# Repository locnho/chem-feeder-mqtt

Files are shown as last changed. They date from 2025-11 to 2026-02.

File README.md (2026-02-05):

# Chem Feeder MQTT

This project provides detection of Pool pH value and report to AquaLinkD via MQTT service.

 * Using a camera to capture the pH controller screen
 * Extract the pH value from the LCD 7 segment display
 * Make a connection to the MQTT service to publish the pH value
 * Report pH controller alarm to MQTT service
 * Report Acid tank level to MQTT service

This work makes use of https://github.com/ved-sharma/Digits_recognition_OpenCV_Python and https://pyimagesearch.com/2018/09/17/opencv-ocr-and-text-recognition-with-tesseract.

Currently, there are two vesions - Python and C++. The Python version is tested and updated. The C++ version is outdated.

# Hardware
The hardware includes:

* Raspberry PI 5
* Hanna BL100 Pool & Spa Ph Controller/Dosing pump
* Arducam for Raspberry Pi Camera Module 3 Wide, 120° IMX708 Manual Focus with M12 Lens (need manual focus)
* RPI heat sink (GeeekPi Aluminum Heatsink Case for Raspberry Pi 5, Aluminum Alloy Armor Case, Passive Cooling Case)

The Raspbery PI 5 also runs AqualinkD.

## Acid Tank Sensor

For Acid Tank sensor, preferred non-contact sensor such:

* XKC-Y25-V Non Contact Liquid Level Sensor (https://www.amazon.com/dp/B0C73F96MF?ref=ppx_yo2ov_dt_b_fed_asin_title) - 2 totals
* KeeYees 10pcs 4 Channels IIC I2C Logic Level Converter Bi-Directional Module 3.3V to 5V Shifter (https://www.amazon.com/dp/B07LG646VS?ref=ppx_yo2ov_dt_b_fed_asin_title)
* IP68 Waterproof Junction Box Housing (https://www.amazon.com/dp/B0CP88ZFWL?ref=ppx_yo2ov_dt_b_fed_asin_title&th=1)
* JST XH 2.54 MM Connector Kit (https://www.amazon.com/dp/B0F5QBR5F4?ref=ppx_yo2ov_dt_b_fed_asin_title&th=1)

This requires a level shifter as the sensor voltage is 5V and RPI 5 requires 3.3V. Then create the adapter board with JST connector. See images below:

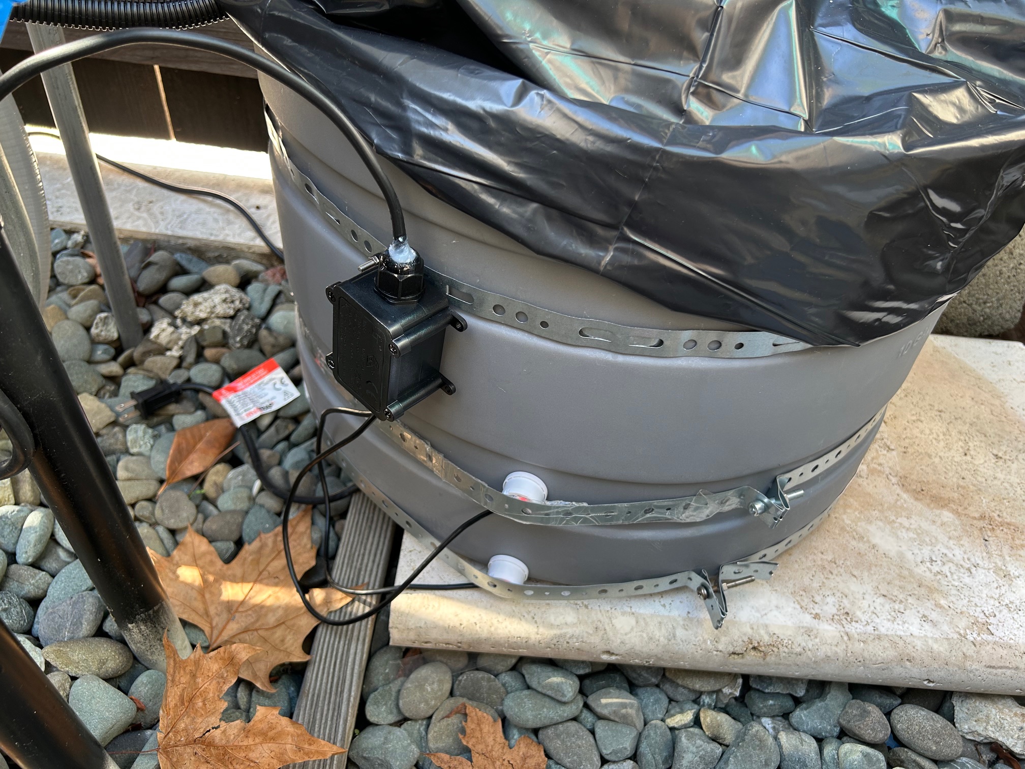
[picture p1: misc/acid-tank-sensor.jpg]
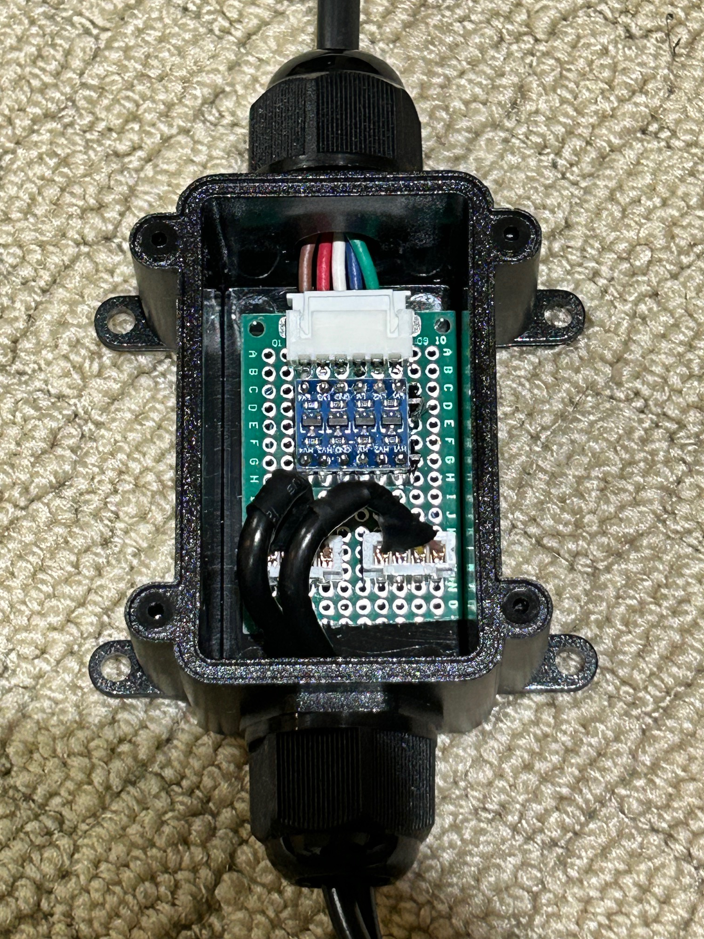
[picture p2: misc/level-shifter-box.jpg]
 | 

To ensure that the junction box is sealed, apply some window sealant on the wire exit.

## Relay & Wiring Diagram

The Acid Dosing Controller can dangerous. As such the following safety measures are employed:

* Acid Dosing Controller is enabled only if the system is in Pool mode
* Acid injector is mounted at the Pool return pipe only
* Sensor is used to ensure that the Acid Dosing Controller is only enabled if the pump is actually running
* A timer to limit the amound of time the Acid Dosing Controller is enabled (avoid hardwaer malfunction and dump a large amount of acid to the pool)

To implement the above, the following hardwares are used:

* A 12V dual relay to disable Acid Dosing Controller if it is NOT in pool mode and no water flow
* A 12V 7 day timer

12V is used as fan are also 12V. Fan can be added to cool the electronic in the enclosure box. The wire diagram is shown below.

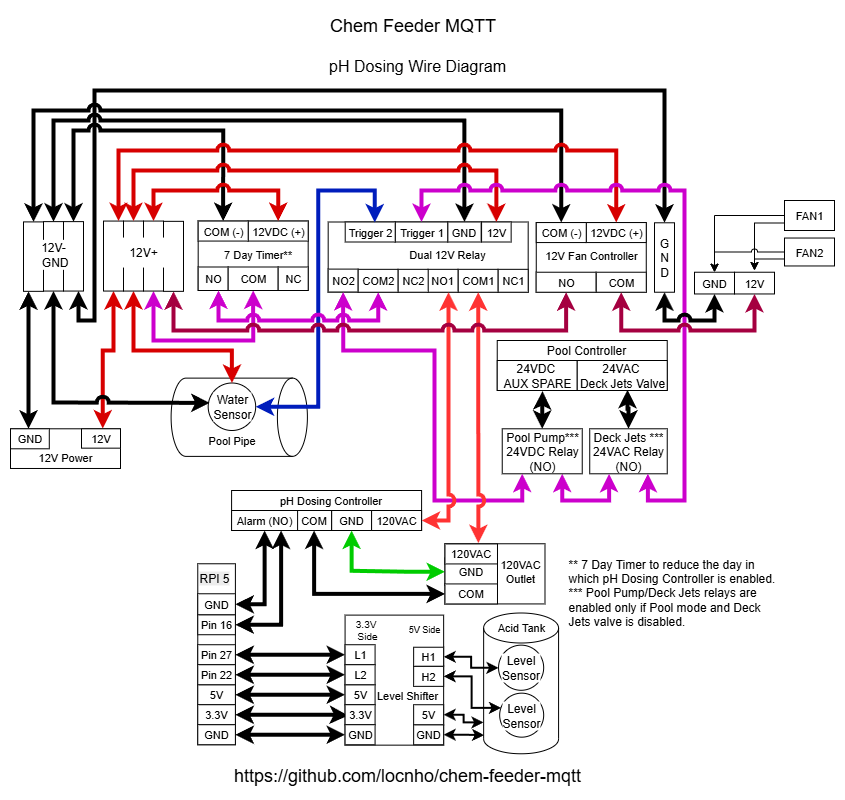
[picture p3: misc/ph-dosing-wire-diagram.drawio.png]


## Mounting

To mount various hardware, use Aluminum DIN Rails (https://en.wikipedia.org/wiki/DIN_rail).

The folder "models" includes various 3D print models for DIN rail mounting.

# pH Report Values

| pH | Description |
|---|---|
|  0.0 | Unit is powered off or no LCD display |
|  1.0 | Unable to detect LCD correctly |
|  2.0 | Unable to detect digits correctly |
|  other values | Values as reported by the unit |

Alarm is reported via the web site interface. Refer to section "Enable pH Data Logging and Web Page".

# How to position the camera?

You need to position the camera such that it captures the outer square outline of the LCD screen.
Refer to image below as an exmpale:

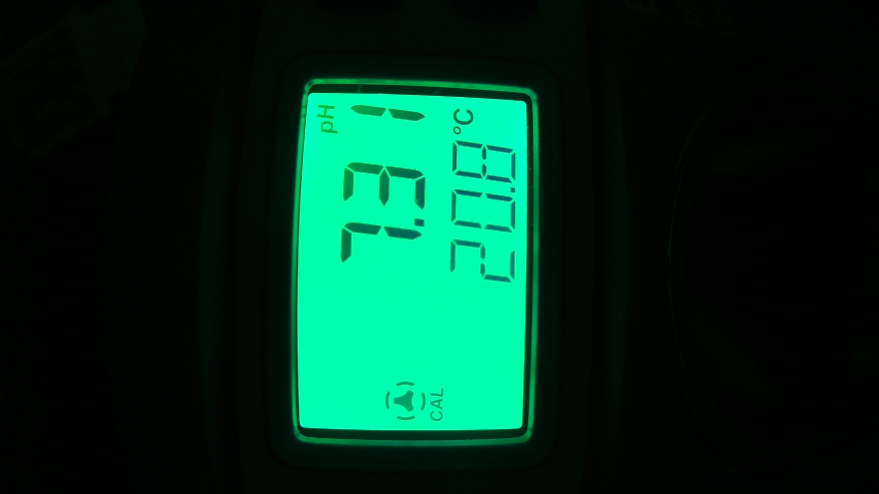
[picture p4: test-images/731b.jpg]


You can run this application to have a live view from browser:

``
    python ./src/rpicam-stream.py
``

Then, on the browser: 

``
    http://<ip address>:5000
``

Below is an image of the pH Controller and RPI camera mount:

To mount the camera over the LCD display, use galvanized interlocking hanger strap. I strapped my pH tank with this. Wrap the hanger strap with some transparent tape. Then bend and squeeze in between the RPI heat sink. There is also mounting 3D models located at folder models. This will make adjust much simple.

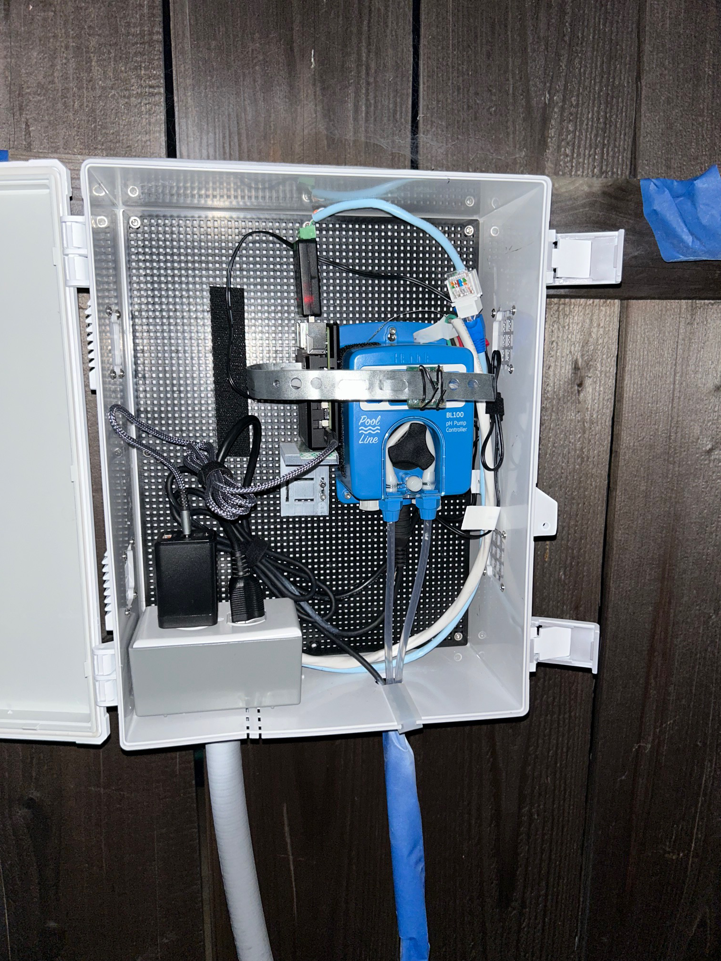
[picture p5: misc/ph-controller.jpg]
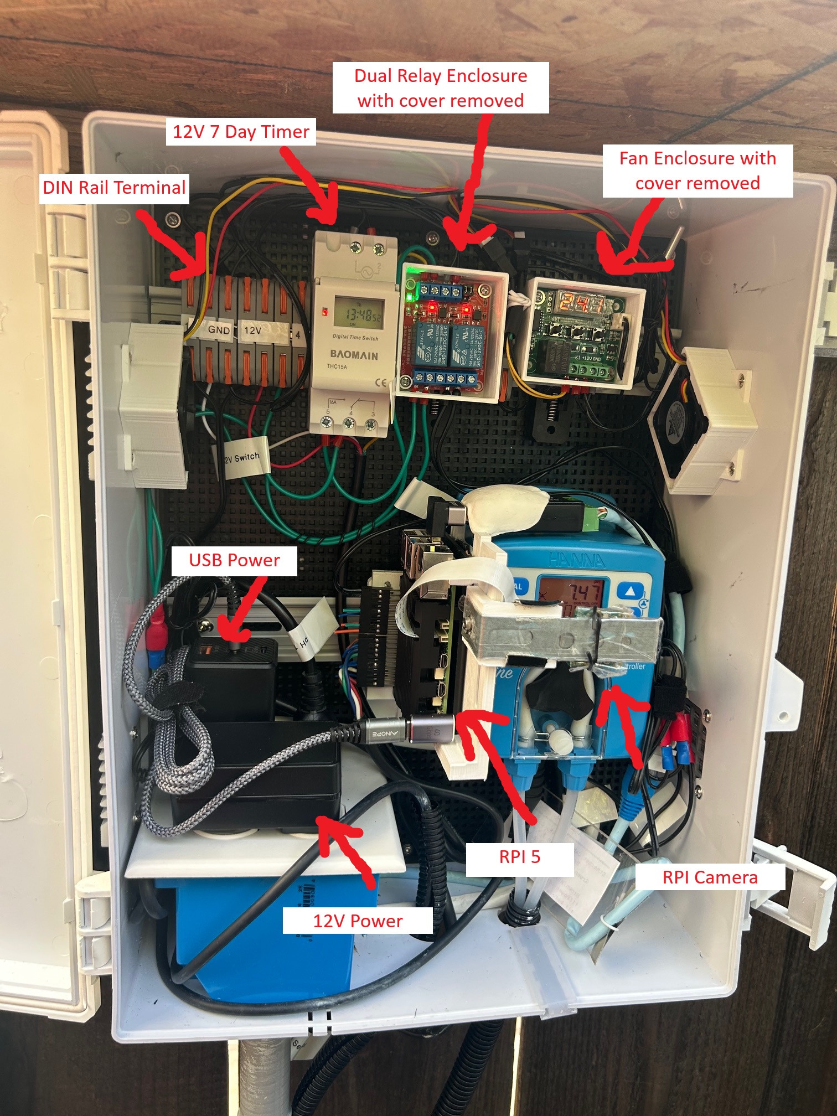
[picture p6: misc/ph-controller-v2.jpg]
 | 

# Configuration with RPI GPIO

GPIO Pin 26 - Alarm: This pin is used to detect pH controller alarm (active high). Connect to controller Normal Open (NO) side.

GPIO Pin 27 - Acid Tank Level1: When this is asserted low, acid tank is below 1%.

GPIO Pin 22 - Acid Tank Level2: When this is asserted low, acid tank is below 50%.

Use this command to enable GPIO:

```
python ./ph-chem-feeder.py --mqtt --password "change to your password" --gpio
```

Use this command to enable and change GPIO pin:

```
python ./ph-chem-feeder.py --mqtt --password "change to your password" --gpio <alarm pin> <acid level1> <acid level2>
```

If you need more options, run with argument "--help".

# Cropping Image

Due to LED of various electronic, you may need to crop the image using the argument "--crop" or cover these LEDs. This argument will crop from four sides.

This command will crop the left side by 400 pixels.

```
python ./ph-chem-feeder.py --crop 400 0 0 0 --mqtt --password "change to your password" 

```

# Configure to start at system boot

See scripts/chem-feeder-mqtt.service

# Enable pH Data Logging and Web Page

To record pH reading for view on a web page, you must enable data logging as follow:

```
python3 ph-chem-feeder.py --gpio --mqtt --password <your password> --gpio --datalog /home/pi/chem-data.bin

```

When pH value is changed from previous value, it saved to the datalog file. All non-zero pH value is only saved every 15 minutes. 

The data can be view from a web page as follow:

```
http://<ip address>:8025

```

Below is an screen shoot of the web page.

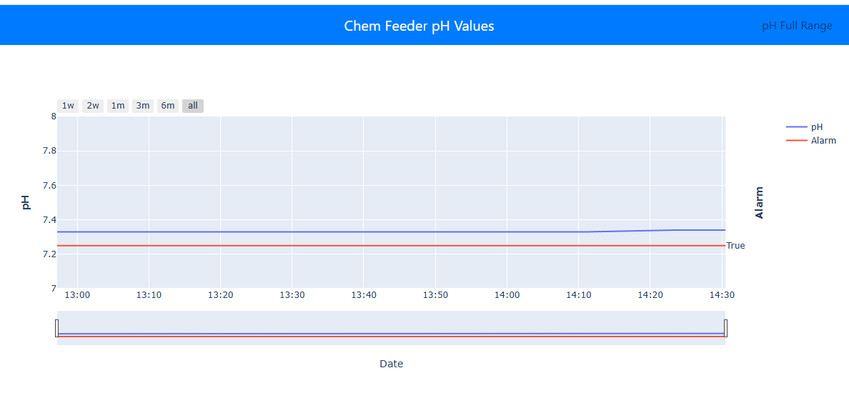
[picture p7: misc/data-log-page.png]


# What to do if it is not detecting digits correctly?

So far, it seems to be functionaly correctly. If you need to tune for your LCD display, try the following:

1. Using rpicam-still application, capture some images.
2. Edit ph-chem-feeder.py and set DBG_LEVEL to "1 + 2 + 4".
3. Disable "PICAM" and "RPIGPIO" by set them to 0.
4. Run this command on your PC or Linux with desktop GUI:

   python ./ph-chem-feeder.py -f "path to your image"

This will show you what the image looks like. 

First, make sure that the detection of the screen is correct. It should crop to just the LCD screen. Refer to image below:

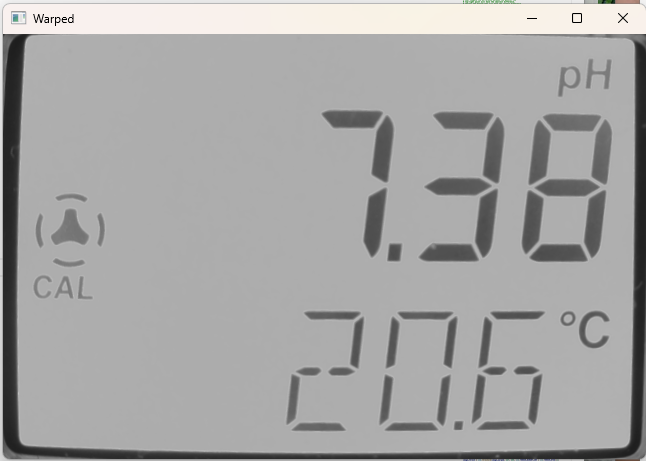
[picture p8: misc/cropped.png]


Second, make sure that each digit has a rectangle draw on it. This indicates that it detected the location of the 3 digits.

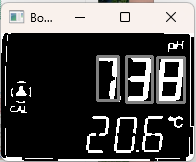
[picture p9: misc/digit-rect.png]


Finally, the decode of each digits. This last part should just work. Otherwise you will need to adjust the detection of the individual segment by changing this code fragment:

```
        # define the set of 7 segments
        segments = [
            ((0, 0), (w, dH)),							 # top
            ((2, 0), (dW + 2, h // 2)),					 # top-left
            ((w - dW - 2, 0), (w, h // 2)), 			 # top-right
            ((0, (h // 2) - dHC), (w, (h // 2) + dHC)),  # center
            ((0, h // 2), (dW, h)),						 # bottom-left
            ((w - dW*2, h // 2), (w - 2, h)),		     # bottom-right
            ((0, h - dH), (w, h))					     # bottom
        ]
```

# Run Regression Testing

To run a regression testing with all images in folder test-images with first 3 letters as digit, issue the following command:

```
    python .\src\ph-chem-feeder.py -r 90 --selftest
    Chem Feeder MQTT
    PASSED 17/17
```

# Background on the Overall Algorithm

The general idea is:

1. Capture 20 images with delay of 50ms
2. Using these images, determine if the LCD is ON or OFF. This is for the case where the LCD is flashing due to alarm.
3. If it is OFF, report 0.0 and stop
4. For image that is not complete black, determine the LCD location and crop 100 pixel borders
5. Determine the contour of the LCD using OpenCV
6. Scale the image to 512 pixel and transpose the LCD image into a rectangle using OpenCV
7. Scale the image to 128 pixel and determine all the LCD digits using OpenCV
8. For each LCD digits, determine whether each segment is ON (white) or OFF (black). Then decode the digit from these on/off segment.
9. If the operation failed to determine the digits or transpose, adjust the black and white binary mapping threshold and try again.
10. If the operation failed to determine the digits, adjust the exposure and try again.
11. Final, try three times.
12. If all failed, report 2.0 for error decoding digits.

# Homebridge MQTT Integration for Acid Tank Level & Alarm

To report Acid Tank Level and Alarm in HomeKit, install the homebridge-mqtt plugin (https://github.com/cflurin/homebridge-mqtt).

The configuration setting:

```
        {
            "name": "mqtt",
            "url": "mqtt://127.0.0.1",
            "port": "1883",
            "username": "pi",
            "password": "password",
            "qos": 0,
            "topic_type": "multiple",
            "topic_prefix": "homebridge",
            "platform": "mqtt"
        }
```

# AquaLinkD Web Page Integration for Acid Tank Level & Alarm

To have Acid Tank Level and Alarm display in AquaLinkD, you need to use this branch:

https://github.com/locnho/AqualinkD/tree/pda-ps6-dev-v3.0.3b

Or you can manual add support to your existent AquaLinkD Web Page:

1. Copy file "web/mqtt_sensors.js" and "web/mqtt.min.js" to "/var/www/aqualinkd"
2. Add below line to "/var/www/aqualinkd/index.html" right above "<script type='text/javascript'>"

   <script scr="mqtt.min.js" type="text/javascript"></script>
3. Add below line to "/var/www/aqualinkd/config.json"

   "external_script":"mqtt_sensors.js",

Or you can just build this and do a "make install".

# ORP Monitor Support

It now supports for MQTT ORP monitor with AquaLinkD. If you publish ORP reading to AquaLinkD, it can monitor ORP values.

 If you want to disable, add argument:

```

    --orp ""

```

# Misc Note

If your camera is mounted at a different direction, use the "-r" parameter to rotate.

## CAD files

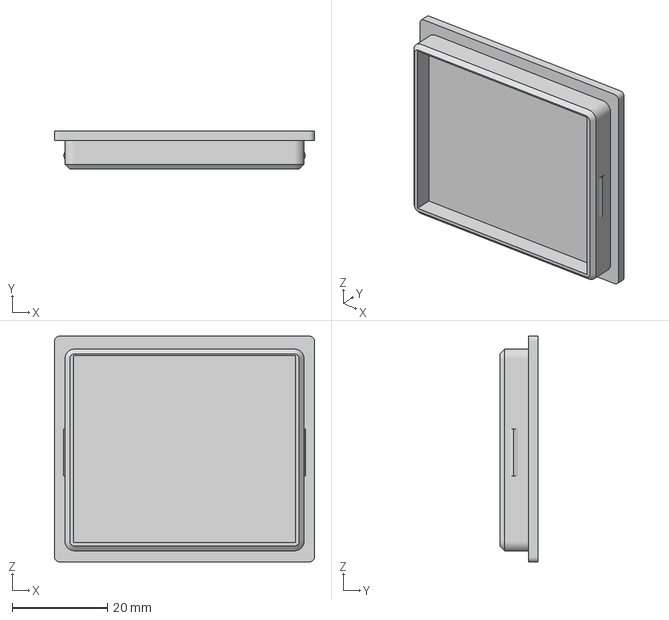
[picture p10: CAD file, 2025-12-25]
models/DIN Rail Fan Enclosure Cover.3mf
54.5 x 8.00 x 47.3 mm

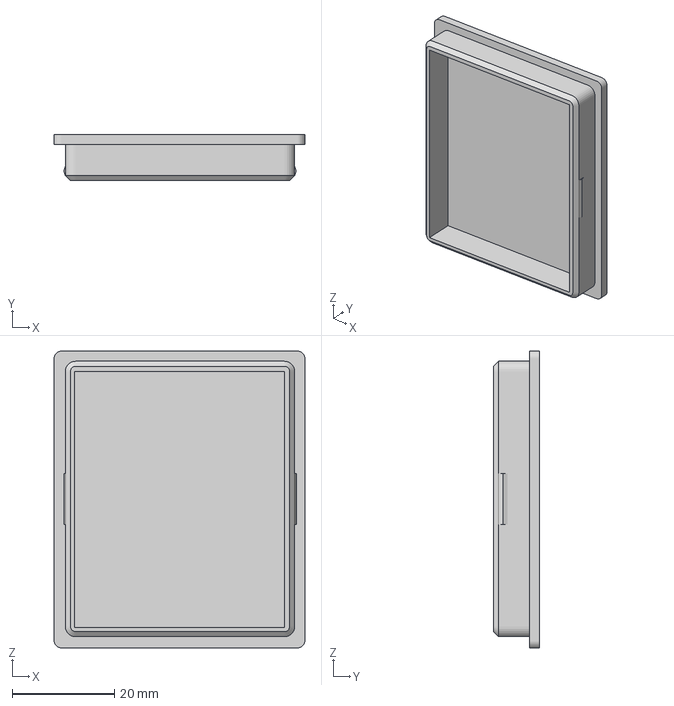
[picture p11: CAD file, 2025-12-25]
models/DIN Rail Dual Relay Cover.3mf
49.0 x 9.00 x 58.0 mm

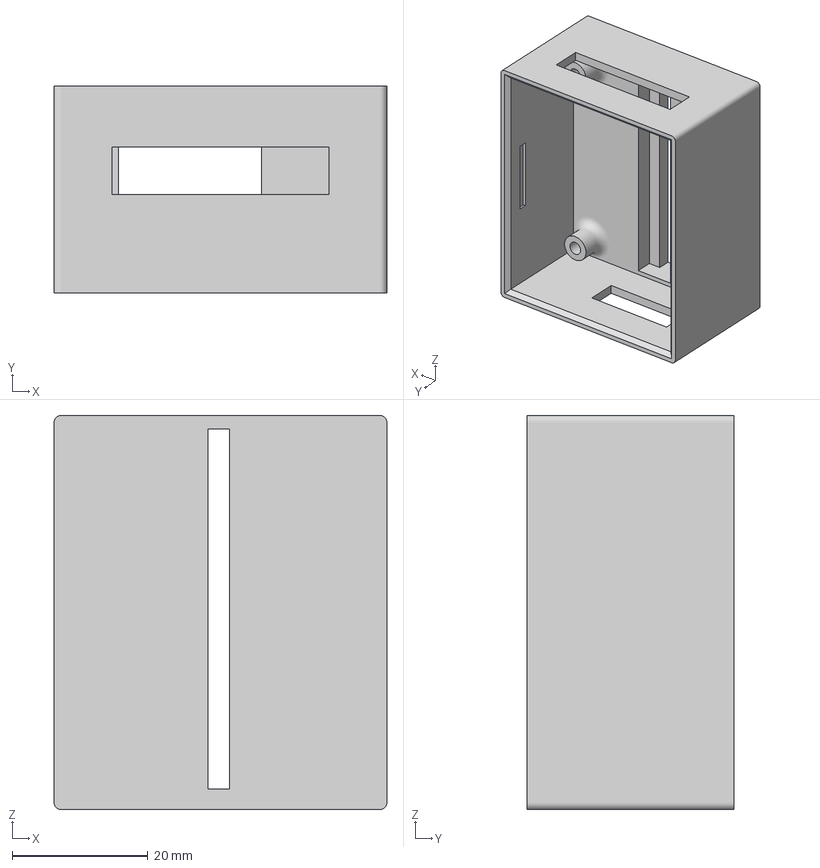
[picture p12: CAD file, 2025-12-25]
models/DIN Rail Dual Relay Enclosure.3mf
49.0 x 30.5 x 58.0 mm

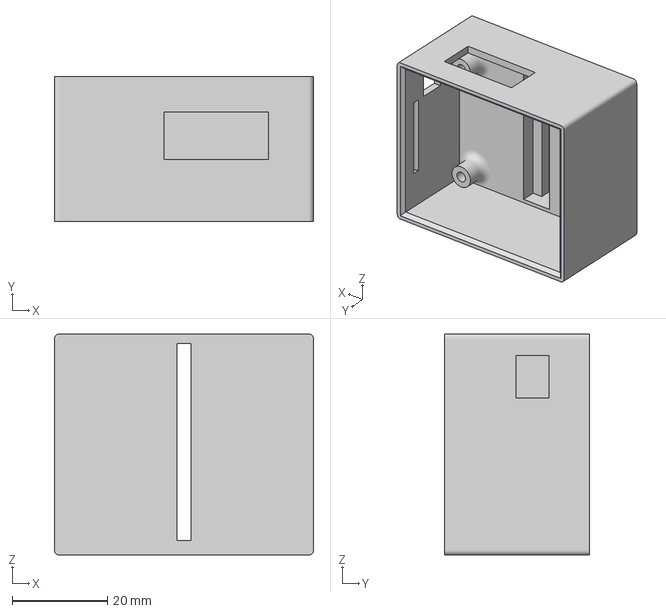
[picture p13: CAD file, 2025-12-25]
models/DIN Rail Fan Controller Enclosure.3mf
54.5 x 30.5 x 46.5 mm

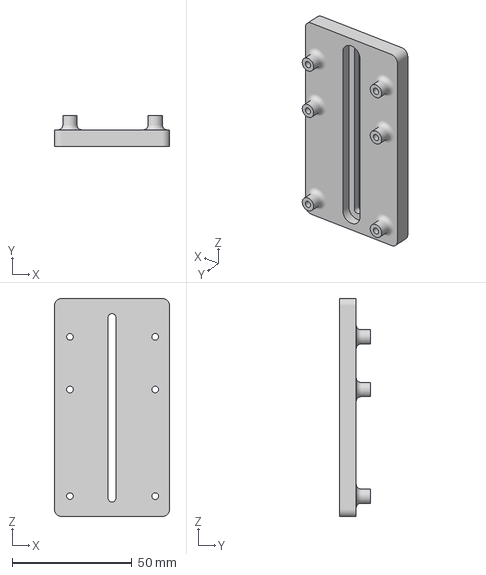
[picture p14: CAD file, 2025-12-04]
models/DIN Rail Dual Relay Mount Extended.3mf
48.1 x 13.0 x 91.0 mm

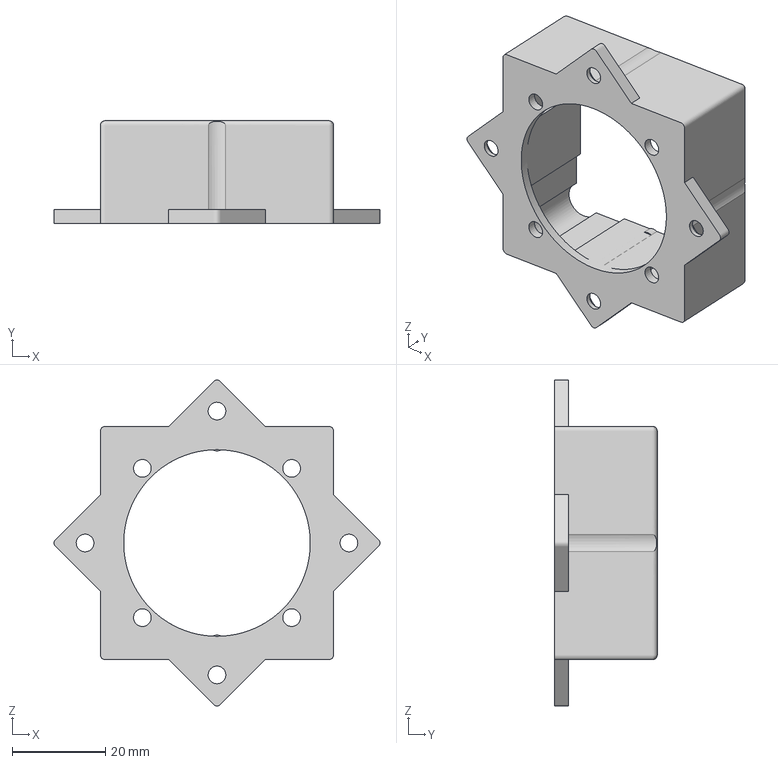
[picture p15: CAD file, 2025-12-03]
models/40mm Fan Mount.3mf
69.9 x 22.0 x 69.9 mm

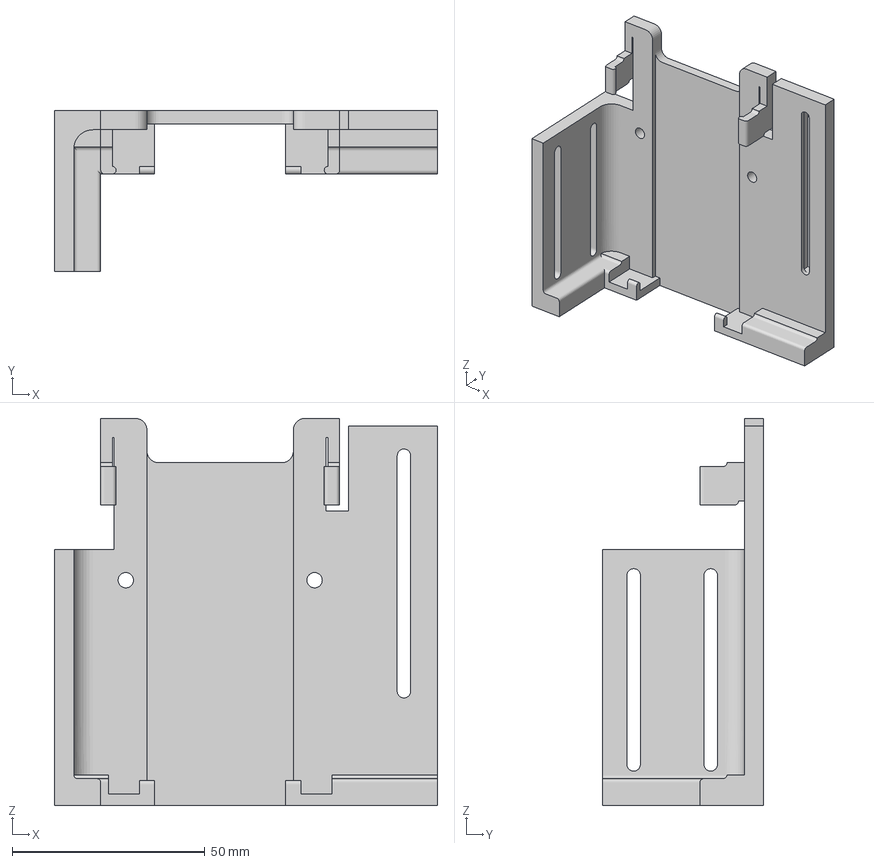
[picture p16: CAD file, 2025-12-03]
models/RPI5 Side Mount.3mf
99.4 x 41.8 x 100.5 mm

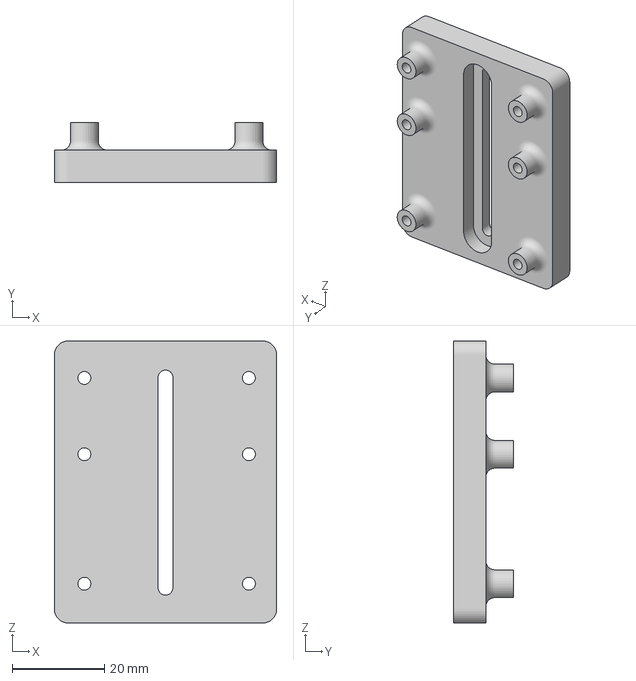
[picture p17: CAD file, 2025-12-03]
models/DIN Rail Dual Relay Mount - 35.5x44.3mf
48.1 x 13.0 x 61.0 mm

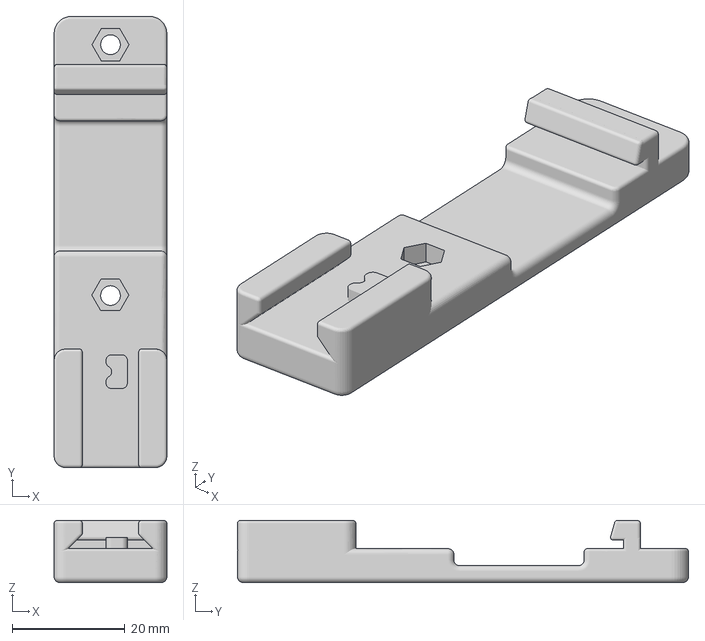
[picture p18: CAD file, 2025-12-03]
models/DIN Mount Clip - Part 2.3mf
20.0 x 80.0 x 11.0 mm

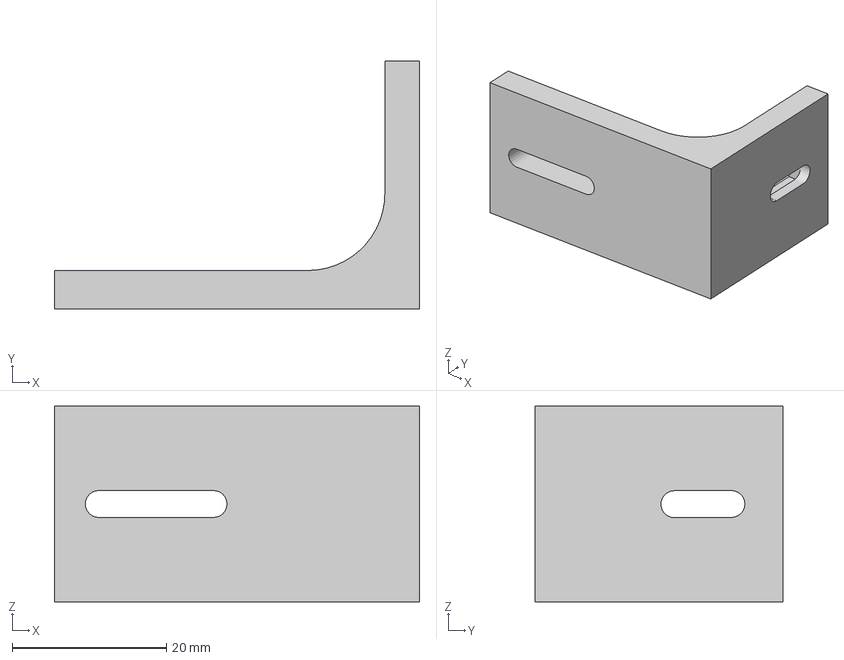
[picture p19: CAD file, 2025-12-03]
models/RPI5 Side Camera Mount.3mf
47.4 x 32.2 x 25.4 mm

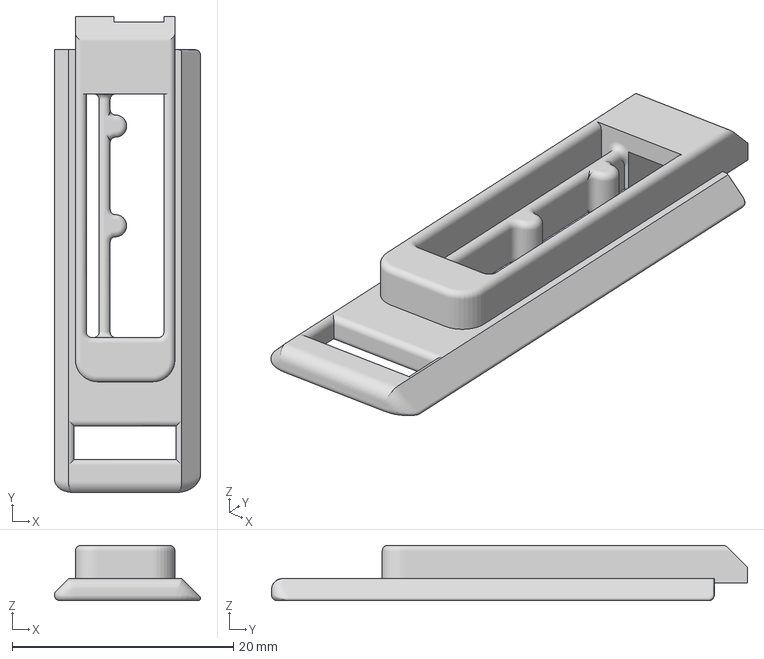
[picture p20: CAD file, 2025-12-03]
models/DIN Mount Clip - Part 1.3mf
13.2 x 43.0 x 5.00 mm

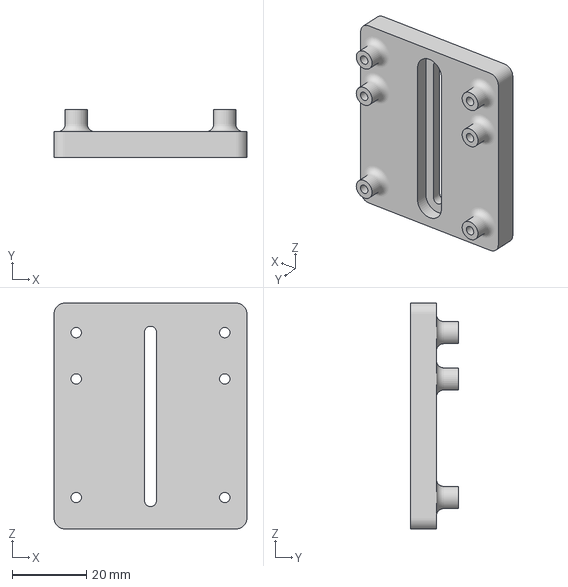
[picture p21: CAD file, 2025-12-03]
models/DIN Rail Dual Relay Mount - 40x32.3mf
52.1 x 13.0 x 61.0 mm

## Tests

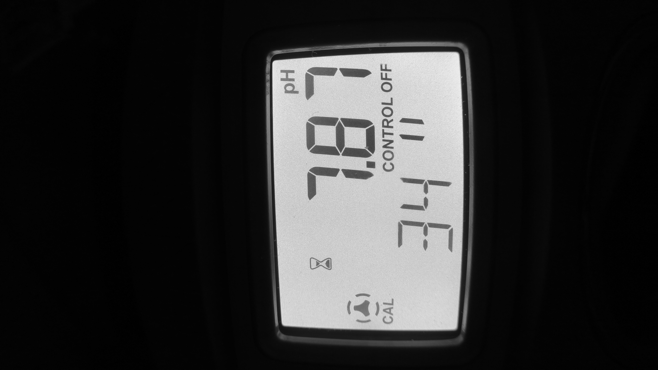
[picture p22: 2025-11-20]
test-images/787b.jpg

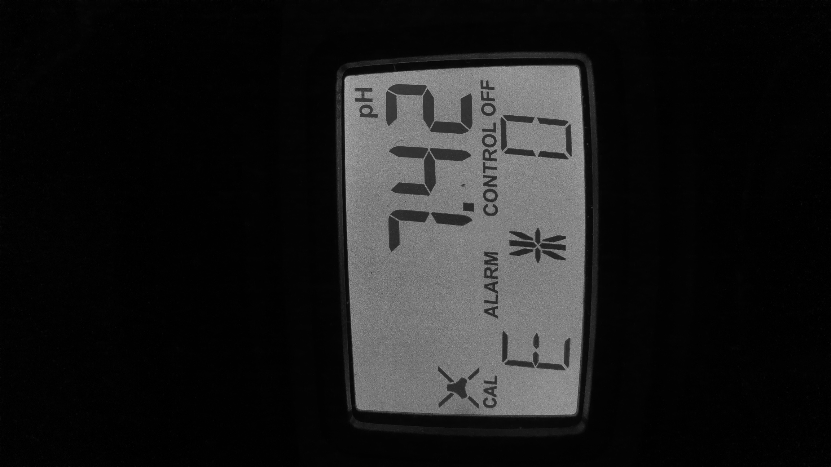
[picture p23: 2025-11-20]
test-images/742o.jpg

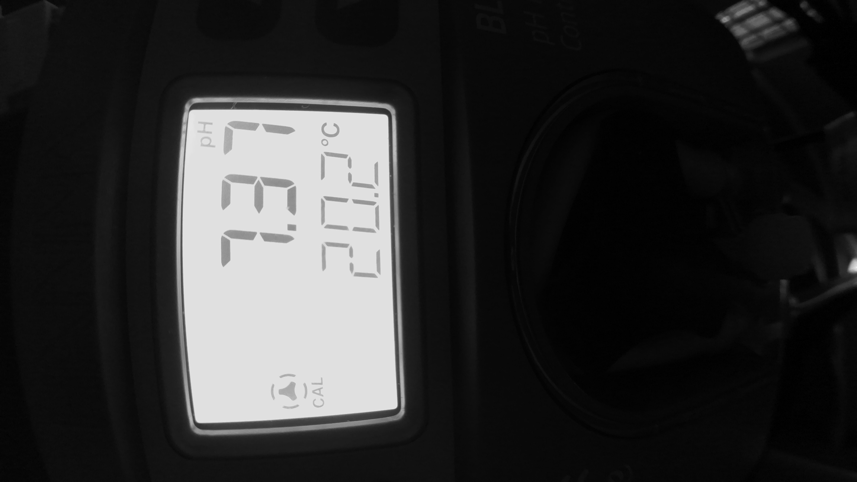
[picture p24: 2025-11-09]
test-images/737f.jpg

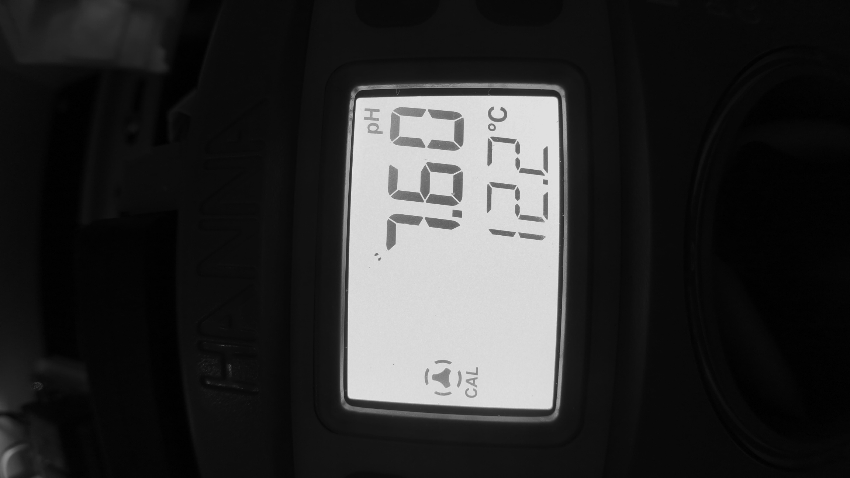
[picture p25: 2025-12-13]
test-images/760b.jpg

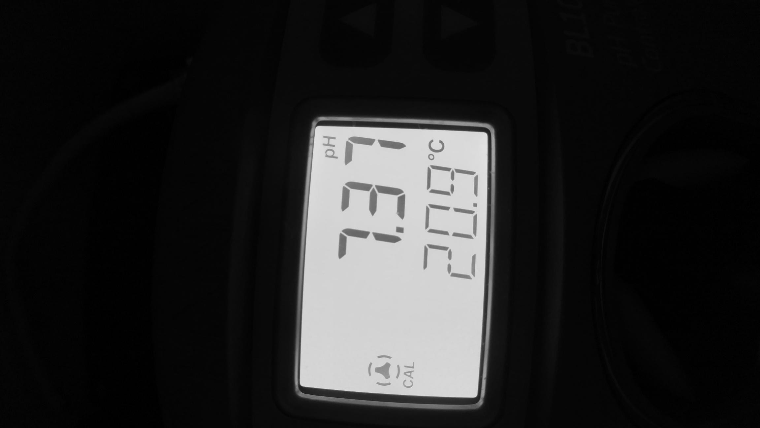
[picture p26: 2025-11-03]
test-images/737c.jpg

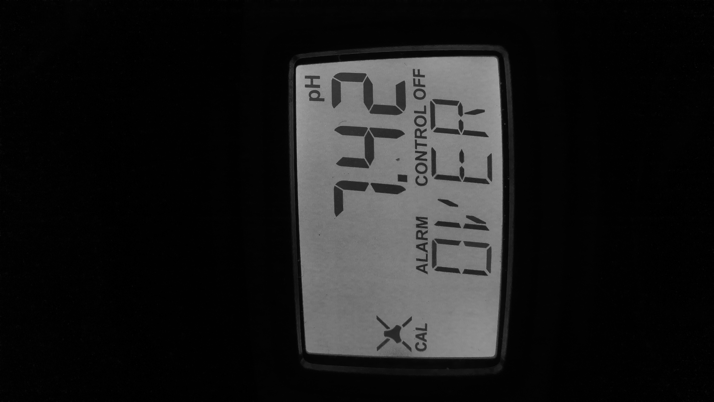
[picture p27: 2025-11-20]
test-images/742s.jpg

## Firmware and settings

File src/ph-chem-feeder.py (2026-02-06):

import argparse
import cv2
import imutils
import numpy as np
#import pytesseract
import time
import os
import csv
import paho.mqtt.client as mqtt
from datetime import datetime, timedelta
from dateutil.relativedelta import relativedelta
import pandas as pd
import math
import glob

import threading
import plotly.io as pio                     # For convert plotly to HTML
import plotly.graph_objects as go
from plotly.subplots import make_subplots
from fastapi import FastAPI
from fastapi.responses import HTMLResponse
import uvicorn
import sqlite3
import serial


PICAM = 1                 # Set to 1 to support RPI Camera, otherise, use the -f argument
RPIGPIO = 1               # Set to 1 to support GPIO pin below. Must include the --gpio argument as well
gpio_alarm_pin = 26       # physical GPIO board number for pH alarm detection (active low). Set to -1 to ignore
gpio_acid_level_pin1 = 27 # physical GPIO board number for acid tank level low. Set to -1 to ignore
gpio_acid_level_pin2 = 22 # physical GPIO board number for acid tank at 50%. Set to -1 to ignore

DBG_LEVEL = 0                       # No debugging
#DBG_LEVEL = 1                      # Show image of detecting the LCD rectangle
#DBG_LEVEL = 2                      # Show image of detecting the digit rectangle
#DBG_LEVEL = 4                      # Show info and image of detection the individual digit
#DBG_LEVEL = 8                      # Show data saving
#DBG_LEVEL = 16                     # Show GPIO info
#DBG_LEVEL = 32                     # Show each iteration of decoding an image
#DBG_LEVEL = 64                     # Show ORP information
#DBG_LEVEL = 1 + 2 + 4 + 8 + 16     # Show all

verbose = 1             # 1 - mimimum
verbose = 1 + 2         # plus MQTT publish
#verbose = 1 + 2 + 4     # plus all MQTT message


def sort_contours(cnts, method="left-to-right"):
	# initialize the reverse flag and sort index
	reverse = False
	i = 0
	# handle if we need to sort in reverse
	if method == "right-to-left" or method == "bottom-to-top":
		reverse = True
	# handle if we are sorting against the y-coordinate rather than
	# the x-coordinate of the bounding box
	if method == "top-to-bottom" or method == "bottom-to-top":
		i = 1
	# construct the list of bounding boxes and sort them from top to
	# bottom
	boundingBoxes = [cv2.boundingRect(c) for c in cnts]
	(cnts, boundingBoxes) = zip(*sorted(zip(cnts, boundingBoxes),
		key=lambda b:b[1][i], reverse=reverse))
	# return the list of sorted contours and bounding boxes
	return (cnts, boundingBoxes)

def order_points(pts):
	# initialzie a list of coordinates that will be ordered
	# such that the first entry in the list is the top-left,
	# the second entry is the top-right, the third is the
	# bottom-right, and the fourth is the bottom-left
	rect = np.zeros((4, 2), dtype = "float32")
	# the top-left point will have the smallest sum, whereas
	# the bottom-right point will have the largest sum
	s = pts.sum(axis = 1)
	rect[0] = pts[np.argmin(s)]
	rect[2] = pts[np.argmax(s)]
	# now, compute the difference between the points, the
	# top-right point will have the smallest difference,
	# whereas the bottom-left will have the largest difference
	diff = np.diff(pts, axis = 1)
	rect[1] = pts[np.argmin(diff)]
	rect[3] = pts[np.argmax(diff)]
	# return the ordered coordinates
	return rect

def four_point_transform(image, pts):
	# obtain a consistent order of the points and unpack them
	# individually
	rect = order_points(pts)
	(tl, tr, br, bl) = rect
	# compute the width of the new image, which will be the
	# maximum distance between bottom-right and bottom-left
	# x-coordiates or the top-right and top-left x-coordinates
	widthA = np.sqrt(((br[0] - bl[0]) ** 2) + ((br[1] - bl[1]) ** 2))
	widthB = np.sqrt(((tr[0] - tl[0]) ** 2) + ((tr[1] - tl[1]) ** 2))
	maxWidth = max(int(widthA), int(widthB))
	# compute the height of the new image, which will be the
	# maximum distance between the top-right and bottom-right
	# y-coordinates or the top-left and bottom-left y-coordinates
	heightA = np.sqrt(((tr[0] - br[0]) ** 2) + ((tr[1] - br[1]) ** 2))
	heightB = np.sqrt(((tl[0] - bl[0]) ** 2) + ((tl[1] - bl[1]) ** 2))
	maxHeight = max(int(heightA), int(heightB))
	# now that we have the dimensions of the new image, construct
	# the set of destination points to obtain a "birds eye view",
	# (i.e. top-down view) of the image, again specifying points
	# in the top-left, top-right, bottom-right, and bottom-left
	# order
	dst = np.array([
		[0, 0],
		[maxWidth - 1, 0],
		[maxWidth - 1, maxHeight - 1],
		[0, maxHeight - 1]], dtype = "float32")
	# compute the perspective transform matrix and then apply it
	M = cv2.getPerspectiveTransform(rect, dst)
	warped = cv2.warpPerspective(image, M, (maxWidth, maxHeight))
	# return the warped image
	return warped

# define the dictionary of digit segments so we can identify each digit
#
#    11111
#   2     3
#   2     3
#   2     3
#   2     3
#    44444
#   5     6
#   5     6
#   5     6
#   5     6
#    77777
#
DIGITS_LOOKUP = {
	(1, 1, 1, 0, 1, 1, 1): 0,
	(0, 0, 1, 0, 0, 1, 0): 1,
	(1, 0, 1, 1, 1, 0, 1): 2,
	(1, 0, 1, 1, 0, 1, 1): 3,
	(0, 1, 1, 1, 0, 1, 0): 4,
	(1, 1, 0, 1, 0, 1, 1): 5,
	(1, 1, 0, 1, 1, 1, 1): 6,
	(1, 0, 1, 0, 0, 1, 0): 7,
	(1, 1, 1, 1, 1, 1, 1): 8,
	(1, 0, 1, 0, 0, 1, 0): 7,
	(1, 1, 1, 1, 1, 1, 1): 8,
	(1, 1, 1, 1, 0, 1, 1): 9
}

ERR_SUCCESS = 0
ERR_LCDOFF = -1
ERR_NODIGITS = -2
ERR_NODIGIT = -3
ERR_NORECT = -4
ERR_NOSCREEN_DETECTED = -5

ERR_NOMQTT = -100

file_name = ""                  # Image name instead camera
rotate = 0                      # Rotate input image
mqtt_pub = 0                    # Publish to MQTT server if 1
mqtt_username = "pi"            # MQTT user name
mqtt_password = "password"      # MQTT password
mqtt_addr = "127.0.0.1"         # MQTT address
mqtt_port = 1883                # MQTT port
mqtt_connected = 0              # Status connection to MQTT
save_filename = ""              # File name to saving image on detect digits failure
first_image = 1                 # Indicate first image capture from camera 
use_gpio = 0                    # Use to GPIO if 1
self_test = False               # Run self test if True
log_data_filename = ""          # File name to log pH data
web_addr = "0.0.0.0"            # Web address to serving pH data (default all interfaces)
web_port = 8025                 # Web port to serving pH data
sample_interval = 30            # Sample interval in second
crop_rect = [0, 0, 0, 0]        # Crop value of all sides
orp_mqtt_topic = "aqualinkd/CHEM/ORP/set" # ORP MQTT topic
swg_mqtt_topic = "aqualinkd/SWG/#"        # SWG MQTT topic
time_mqtt_topic = "datetime"    # Date time topic
orp_alarm_mqtt_topic = "homebridge/to/set"

orp_reading = 0.0
orp_reading_ts = None
swg_pct_reading = 0
swg_pct_reading_ts = None
orp_alarm = 0
orp_alarm_ts = None

def app_parser_arguments():
    global file_name
    global rotate
    global mqtt_pub
    global mqtt_username
    global mqtt_password
    global mqtt_addr
    global mqtt_port
    global save_filename
    global use_gpio
    global self_test
    global log_data_filename
    global web_addr
    global web_port
    global gpio_alarm_pin
    global gpio_acid_level_pin1
    global gpio_acid_level_pin2
    global sample_interval
    global verbose
    global crop_rect
    global orp_mqtt_topic
    global swg_mqtt_topic
    global time_mqtt_topic
    global orp_alarm_mqtt_topic

    parser = argparse.ArgumentParser(description='Chem Feeder MQTT')
    parser.add_argument('-f','--file', help='Input image file', default=file_name)
    parser.add_argument('-r','--rotate', type=int, help='Rotate image', default=rotate)
    parser.add_argument('--mqtt', help='Publish to MQTT', action="store_true")
    parser.add_argument('--user', help='MQTT user', default=mqtt_username)
    parser.add_argument('--password', help='MQTT password', default=mqtt_password)
    parser.add_argument('--addr', help='MQTT address', default = "127.0.0.1")
    parser.add_argument('--port', type=int, help='MQTT port', default=1883)
    parser.add_argument('--save', type=str, help='If provided and detection failure, save capture image to file', default="")
    parser.add_argument('--gpio', type=int, nargs="*", help=f"Enable GPIO for alarm,acid level1, and acid level2 detection\nDefault is {gpio_alarm_pin} {gpio_acid_level_pin1} {gpio_acid_level_pin2}")
    parser.add_argument('--selftest', action="store_true", help="Run self-test and exit", default=False)
    parser.add_argument('--datalog', type=str, help="File name for pH data logging/web site", default=log_data_filename)
    parser.add_argument('--webaddr', type=str, help="Web server address", default=web_addr)
    parser.add_argument('--webport', type=str, help="Web server port", default=web_port)
    parser.add_argument('--sample', type=int, help="Sample interval in seconds", default=sample_interval)
    parser.add_argument('-v', action="store_true", help="Verbose level 1 and 2")
    parser.add_argument('-vv', action="store_true", help="Verbose level 1, 2, and 4")
    parser.add_argument('--crop', type=int, nargs=4, help=F"Amount of pixel to crop on left, top, right, bottom\nDefault is 0, 0, 0, 0.\nCrop is before rotate.")
    parser.add_argument('--orp', type=str, help="ORP monitor MQTT topic. Set to \"\" to disable", default=orp_mqtt_topic)
    parser.add_argument('--swg', type=str, help="SWG monitor MQTT topic. Set to \"\" to disable", default=swg_mqtt_topic)
    parser.add_argument('--time', type=str, help="Set MQTT time topic. Set to \"\" to disable", default=time_mqtt_topic)
    parser.add_argument('--orpalarm', type=str, help="Set MQTT ORP alarm topic. Set to \"\" to disable", default=orp_alarm_mqtt_topic)

    args = parser.parse_args()
    file_name = args.file
    rotate = args.rotate
    mqtt_pub = args.mqtt
    mqtt_username = args.user
    mqtt_password = args.password
    mqtt_addr = args.addr
    mqtt_port = args.port
    save_filename = args.save
    self_test = args.selftest
    log_data_filename = args.datalog
    web_addr = args.webaddr
    web_port = args.webport
    if args.gpio is not None:
        use_gpio = 1
        if len(args.gpio) == 3:
            gpio_alarm_pin = args.gpio[0]
            gpio_acid_level_pin1 = args.gpio[1]
            gpio_acid_level_pin2 = args.gpio[2]
    sample_interval = args.sample
    if args.vv:
        verbose = 1 + 2 + 4
    elif args.v:
        verbose = 1 + 2
    if args.crop is not None:
        crop_rect = [args.crop[0], args.crop[1], args.crop[2], args.crop[3]]
    if args.orp is not None:
        orp_mqtt_topic = args.orp
    if args.swg is not None:
        swg_mqtt_topic = args.swg
    if args.time is not None:
        tim_mqtt_topic = args.time
    if args.orpalarm is not None:
        orp_alarm_mqtt_topic = args.orpalarm


def sort_contours_top_to_bottom(contours):
    # Create a list of (contour, bounding box) tuples
    bounding_boxes = [cv2.boundingRect(c) for c in contours]
    (contours, bounding_boxes) = zip(*sorted(zip(contours, bounding_boxes), key=lambda b: b[1][1])) # b[1][1] is the y-coordinate
    return contours, bounding_boxes


def sort_contours_left_to_right_within_lines(contours, bounding_boxes, y_threshold=10):
    sorted_contours = []
    current_line = []

    if not contours:
        return [], []

    # Start with the first contour
    current_line_y = bounding_boxes[0][1]

    for i in range(len(contours)):
        contour = contours[i]
        bbox = bounding_boxes[i]

        # If the current contour is within the y_threshold of the current line
        if abs(bbox[1] - current_line_y) <= y_threshold:
            current_line.append((contour, bbox))
        else:
            # Sort the completed line by x-coordinate
            current_line.sort(key=lambda item: item[1][0]) # item[1][0] is the x-coordinate
            sorted_contours.extend([item[0] for item in current_line]) # Add sorted contours to the final list

            # Start a new line
            current_line = [(contour, bbox)]
            current_line_y = bbox[1]

    # Sort and add the last line
    current_line.sort(key=lambda item: item[1][0])
    sorted_contours.extend([item[0] for item in current_line])

    return sorted_contours, [cv2.boundingRect(c) for c in sorted_contours] # Return sorted contours and their new bounding boxes


def extract_digits_once(image, threshold_val = 64, blurr_val = 5, morpho = False, brightness = True):
    if crop_rect[0] > 0 or crop_rect[1] > 0 or crop_rect[2] > 0 or crop_rect[3] > 0:
        img_height, img_width = image.shape
        image = image[crop_rect[1]:img_height - crop_rect[3], crop_rect[0]:img_width - crop_rect[2]]
        if DBG_LEVEL & 1:
            cv2.imshow('Crop', image) 
            cv2.waitKey(0)
            cv2.destroyAllWindows()

    if rotate != 0:
	    image = imutils.rotate_bound(image, rotate)

    image_bw = cv2.threshold(image, threshold_val, 255, cv2.THRESH_BINARY)[1]
    img_height, img_width = image_bw.shape
    contours, _ = cv2.findContours(image_bw, cv2.RETR_EXTERNAL, cv2.CHAIN_APPROX_SIMPLE)
    if contours:
        largest_contour = max(contours, key=cv2.contourArea)
        x, y, w, h = cv2.boundingRect(largest_contour)
        border = 100
        if x >= border:
            x -= border
            w += border
        else:
            w += x
            x = 0

        if y >= border:
            y -= border
            h += border;
        else:
            h += y
            y = 0
        x2 = x + w
        if x2 + border >= img_width:
            x2 = img_width - 1
        else:
            x2 += border
        y2 = y + h
        if y2 + border >= img_height:
            y2 = img_height - 1
        else:
            y2 += border
        if DBG_LEVEL & 1:
            image_w_bbox = cv2.rectangle(image_bw,(x, y),(x2, y2),(128, 128, 128),2)
            cv2.imshow('Contour', imutils.resize(image_w_bbox, height=1024))
            cv2.waitKey(0)
            cv2.destroyAllWindows()
        image = image[y:y+h + border, x:x+w + border]

    image_resize = imutils.resize(image, height=512)
    if DBG_LEVEL & 1:
        cv2.imshow('Image', image_resize) 
        cv2.waitKey(0)
        cv2.destroyAllWindows()

    image_blurred = cv2.GaussianBlur(image_resize, (blurr_val, blurr_val), 0)
    image_edged = cv2.Canny(image_blurred, 50, 200, 255)
    if DBG_LEVEL & 1:
        cv2.imshow('Edged', image_edged) 
        cv2.waitKey(0)
        cv2.destroyAllWindows()

    cnts = cv2.findContours(image_edged.copy(), cv2.RETR_EXTERNAL, cv2.CHAIN_APPROX_SIMPLE)
    cnts = imutils.grab_contours(cnts)
    cnts = sorted(cnts, key=cv2.contourArea, reverse=True)
    displayCnt = None
    for c in cnts:
        # approximate the contour
        peri = cv2.arcLength(c, True)
        approx = cv2.approxPolyDP(c, 0.02 * peri, True)
        # if the contour has four vertices, then we have found the thermostat display
        if len(approx) == 4:
            displayCnt = approx
            break;

    if displayCnt is None:
        return ERR_NOSCREEN_DETECTED, 0.0

    image_warped = four_point_transform(image_resize, displayCnt.reshape(4, 2))
    if DBG_LEVEL & 1:
        cv2.imshow('Warped', image_warped) 
        cv2.waitKey(0)
        cv2.destroyAllWindows()

    for i in range(2):
        image_resized = imutils.resize(image_warped, height=128)
        #
        # First attempt will not sharpen the image.
        # Second attempt will try with sharpen the image.
        if i == 1:
            kernel = np.array([[0, -1, 0], [-1, 5, -1], [0, -1, 0]])
            image_resized = cv2.filter2D(image_resized, -1, kernel)

        if brightness:
            alpha = 1.05	# Adjust contrast (e.g., 1.5 for higher contrast)
            beta = -115		# Adjust brightness (e.g., 30 for brighter)
            # Apply the linear transformation: new_image = alpha * original_image + beta
            image_resized = cv2.convertScaleAbs(image_resized, alpha=alpha, beta=beta)
            if DBG_LEVEL & 2:
                cv2.imshow('Brightness', imutils.resize(image_resized, 256))
                cv2.waitKey(0)
                cv2.destroyAllWindows()

        # convert image to threshold and then apply a series of morphological
        # operations to cleanup the thresholded image
        image_thresh = cv2.threshold(image_resized, 127, 255, cv2.THRESH_BINARY_INV | cv2.THRESH_OTSU)[1]
        if DBG_LEVEL & 2:
            cv2.imshow('Thresh', imutils.resize(image_thresh, 256))
            cv2.waitKey(0)
            cv2.destroyAllWindows()
        if morpho:
            kernel = cv2.getStructuringElement(cv2.MORPH_ELLIPSE, (1, 5))       
            image_thresh = cv2.morphologyEx(image_thresh, cv2.MORPH_OPEN, kernel)
            if DBG_LEVEL & 2:
                cv2.imshow('Morpho', image_thresh)
                cv2.waitKey(0)
                cv2.destroyAllWindows()

        kernel = np.ones((3,3),np.uint8)
        image_dilation = cv2.dilate(image_thresh, kernel, iterations = 1)
        image_erosion = cv2.erode(image_dilation, kernel, iterations = 1)
        if DBG_LEVEL & 2:
            cv2.imshow('Erosion', imutils.resize(image_erosion, 256))
            cv2.waitKey(0)
            cv2.destroyAllWindows()

        # Crop off the bottom row
        img_height, img_width = image_erosion.shape
        image_erosion = image_erosion[0:int(img_height*.75), 0:img_width]

        # find contours in the thresholded image, and put bounding box on the image
        cnts = cv2.findContours(image_erosion.copy(), cv2.RETR_EXTERNAL, cv2.CHAIN_APPROX_NONE)
        cnts = imutils.grab_contours(cnts)

        if DBG_LEVEL & 2:
            image_w_bbox = image_erosion.copy()
        digitCnts = []
        for c in cnts:
            # compute the bounding box of the contour
            (x, y, w, h) = cv2.boundingRect(c)
            if DBG_LEVEL & 2:
                print(f"X {x} Y {y} W {w} H {h}")
                # image_w_bbox = cv2.rectangle(image_w_bbox,(x, y),(x+w, y+h),(128, 128, 128),2)
            # if the contour is sufficiently large, it must be a digit
            if (w >= 7 and w <= 60) and (h >= 40 and h <= 55):
                digitCnts.append(c)
                if DBG_LEVEL & 2:
                    print(f"Found: X {x} Y {y} W {w} H {h}")
                    image_w_bbox = cv2.rectangle(image_w_bbox,(x, y),(x+w, y+h),(128, 128, 128),2)

        # print(len(digitCnts))
        if len(digitCnts) == 3:
            break

        if DBG_LEVEL & 2:
            cv2.imshow('Boxed', image_w_bbox) 
            cv2.waitKey(0)
            cv2.destroyAllWindows()

    # sort the contours from left-to-right
    if len(digitCnts) <= 0:
        return ERR_NORECT, 0.0

    #digitCnts = sort_contours(digitCnts, method="left-to-right")[0]
    y_sorted_contours, y_sorted_bboxes = sort_contours_top_to_bottom(digitCnts)
    final_sorted_contours, final_sorted_bboxes = sort_contours_left_to_right_within_lines(y_sorted_contours, y_sorted_bboxes)
    digits = []
    # loop over each of the digits
    for c in final_sorted_contours:
        # extract the digit ROI
        (x, y, w, h) = cv2.boundingRect(c)

        if w <= 15:
            digits.append(1)
            continue

        roi = image_erosion[y:y + h, x:x + w]
        if DBG_LEVEL & 4:
            cv2.imshow('Digit', imutils.resize(roi, 256))
            cv2.waitKey(0)
            cv2.destroyAllWindows()

        # compute the width and height of each of the 7 segments we are going to examine
        (roiH, roiW) = roi.shape
        (dW, dH) = (int(roiW * 0.25), int(roiH * 0.15)) # Segment 15% height, 25% width
        dHC = int(roiH * 0.05)						  # Seg,emt 10% for center

        # define the set of 7 segments
        segments = [
            ((0, 0), (w, dH)),							 # top
            ((2, 0), (dW + 2, h // 2)),					 # top-left
            ((w - dW - 2, 0), (w, h // 2)), 			 # top-right
            ((0, (h // 2) - dHC), (w, (h // 2) + dHC)),  # center
            ((0, h // 2), (dW, h)),						 # bottom-left
            ((w - dW*2 + 2, h // 2), (w - 2, h)),	     # bottom-right
            ((0, h - dH), (w, h))					     # bottom
        ]

        on = [0] * len(segments)
        # loop over the segments
        for (i, ((xA, yA), (xB, yB))) in enumerate(segments):
            # extract the segment ROI, count the total number of thresholded pixels
            # in the segment, and then compute the area of the segment
            segROI = roi[yA:yB, xA:xB]

            total = cv2.countNonZero(segROI)
            area = (xB - xA) * (yB - yA)
            # if the total number of non-zero pixels is greater than
            # 50% of the area, mark the segment as "on"
            if area > 0.0 and (total / float(area)) > 0.4:
                on[i]= 1

            if DBG_LEVEL & 4:
                roi_w_bbox = cv2.rectangle(roi.copy(),(xA, yA),(xB, yB),(128, 128, 128),1)
                print(f"Segment {i+1}: {on[i]}")
                cv2.imshow(f"Segment {i+1}: {on[i]}", imutils.resize(roi_w_bbox, 256))
                cv2.waitKey(0)
                cv2.destroyAllWindows()

        # lookup the digit
        if DBG_LEVEL & 4:
            print(on)
        try:
            digit = DIGITS_LOOKUP[tuple(on)]
            digits.append(digit)
        except:            
            if DBG_LEVEL & 4:
                print("Un-expected digit loopkup")
            return ERR_NODIGIT, 0.0

        if len(digits) == 3:
            break

    if len(digits) == 3:
        ph = (digits[0] * 100 + digits[1] * 10 + digits[2]) / 100.0
        return ERR_SUCCESS, ph

    if DBG_LEVEL & 4:
        print("Un-expected digits: ", end="")
        print(digits)
    return ERR_NODIGITS, 0.0
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

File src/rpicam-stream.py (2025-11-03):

from flask import Flask, Response
from picamera2 import Picamera2
import cv2

app = Flask(__name__)
picam2 = Picamera2()
picam2.configure(picam2.create_video_configuration(main={"size": (2304, 1296)}))
picam2.start()

def generate_frames():
    while True:
        frame = picam2.capture_array()
        ret, buffer = cv2.imencode('.jpg', frame)
        frame_bytes = buffer.tobytes()
        yield (b'--frame\r\n'
               b'Content-Type: image/jpeg\r\n\r\n' + frame_bytes + b'\r\n')

@app.route('/')
def index():
    return Response(generate_frames(), mimetype='multipart/x-mixed-replace; boundary=frame')

if __name__ == '__main__':
    app.run(host='0.0.0.0', port=5000, debug=False)

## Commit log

2025-11-03 Add GPIO detection of power/alarm
2025-11-03 Add live camera stream python file
2025-11-04 Support ignore GPIO pin if set to 0. Delay longer between checking if LCD is off or powered off.
2025-11-07 Fix detect power off on day time Send 2.0 when there is error condition detected Send 1.0 when there is an alarm detected
    [ph-chem-feeder.py]
2025-11-09 Fix detection of 7.40 reading
    [ph-chem-feeder.py]
2025-11-11 Add mounting 3D model
    Add mounting 3D model and update instruction
    [rpi5-arm.stl, rpi5-side-mount.stl]
2025-11-12 Fix failure with test image 732
    [ph-chem-feeder.py]
2025-11-13 Add retry to detection Change to 15 seconds on LCD off between samples Change to 10 seconds on LCD on between samples
2025-11-16 Fix disable data log Fix binding by allow for address re-use
    [ph-chem-feeder.py]
2025-11-16 Filter out not LCD images
2025-11-17 Adjust pH reading print
2025-11-18 * Update pH site page * Fix GPIO for ignore (use -1) * If LCD is off, show alarm as 0
    [ph-chem-feeder.py]
2025-11-22 Clean up GPIO Support GPIO pin set in argument Fix back up data log file Change time between sample to 15 seconds
    [ph-chem-feeder.py]
2025-11-22 Support control sample interval from argument
2025-11-23 Fix rotate data Fix save data on change only. If data is same and non-zero, save every hour. Add print verbose control from argument
    [ph-chem-feeder.py]
2025-11-23 Add acid tank sensor image
2025-11-23 Update description on acid level sensor
2025-11-26 Fix parsing GPIO argument error Sort camera images with most white pixel first
    [ph-chem-feeder.py]
2025-11-30 Fix saving and rotate data file
    [ph-chem-feeder.py]
2025-11-30 Fix reporting Acid Tank Level when on
    [ph-chem-feeder.py]
2025-12-01 Support cropping image before rotate
    This is required as circuit board LED provides enough light to affect image detection
2025-12-01 Fix log data file name
    [ph-chem-feeder.py]
2025-12-03 Fix image preview on crop Print percentage of white on LCD off detection if debug enabled
    [ph-chem-feeder.py]
2025-12-03 Update documentation
    Move support file to misc
    Add more 3D models
    Update README.md
    [40mm Fan Mount.3mf, DIN Mount Clip - Part 1.3mf, DIN Mount Clip - Part 2.3mf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]
2025-12-04 Update wire diagram
    Update wire diagram
    Add another longer model for dual relay
    [DIN Rail Dual Relay Mount Extended.3mf]
2025-12-08 Switch data log to SQLite database
2025-12-09 Fix web site data timezone issue
    [ph-chem-feeder.py]
2025-12-09 Misc fix due to merge issue
    [ph-chem-feeder.py]
2025-12-09 Fix merge issue #2
    [ph-chem-feeder.py]
2025-12-09 Fix data log every 15 minutes
    [ph-chem-feeder.py]
2025-12-11 Update wire diagram for 12V Update description
2025-12-25 Fix GPIO for alarm Change default alarm pin to 26 Active high Update README.md accordingly
    [ph-chem-feeder.py]
2025-12-25 Update controller image and models
    Update controller image
    Add PCB enclosure with cover
    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
    [DIN Rail Dual Relay Cover.3mf, DIN Rail Dual Relay Enclosure.3mf, DIN Rail Fan Controller Enclosure.3mf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]
2026-01-02 Minor update to wire diagram
2026-01-24 Fix ORP reporting Change log bad image file name
    [ph-chem-feeder.py]
2026-01-24 Fix HTML minor issue
    [ph-chem-feeder.py]
2026-01-30 Fix MQTT failure at start up by reconnect
    [ph-chem-feeder.py]
2026-04-17 For ORP graph, down sample to reduce file size
2026-04-17 Update the ORP sample time for HTML graph
